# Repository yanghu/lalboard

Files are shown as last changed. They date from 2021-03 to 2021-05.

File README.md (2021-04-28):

##### lalboard - A 3D-printed keyboard inspired by the DataHand.

Note: The v2 branch has been deprecated in favor of the [v2_no_stls](https://github.com/JesusFreke/lalboard/tree/v2_no_stls) branch.

The new branch has the exported stls in a separate repository, to help avoid large checkouts when cloning
the base repository.

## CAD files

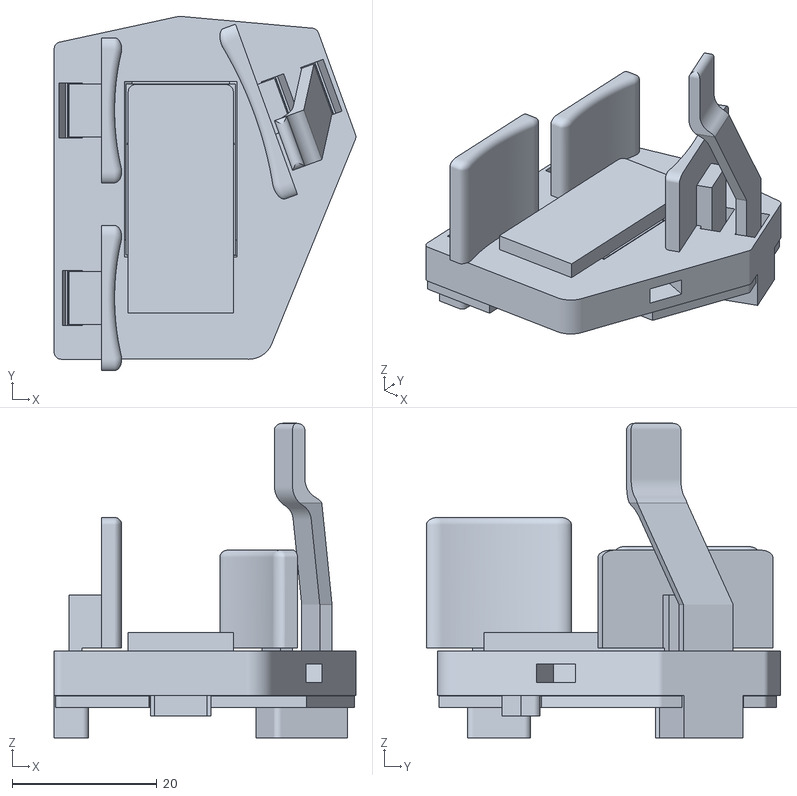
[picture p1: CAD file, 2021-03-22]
stls/thumb_cluster_left_assembly.stl
41.6 x 48.8 x 43.4

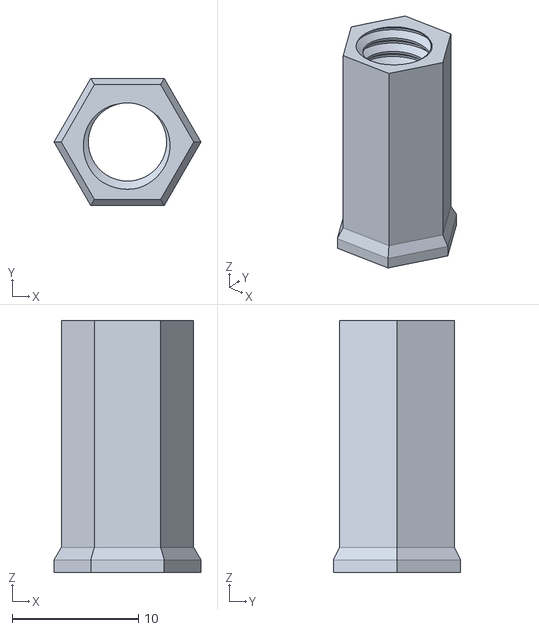
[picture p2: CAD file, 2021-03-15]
stls/screw_base_20.stl
11.7 x 10.1 x 20.0

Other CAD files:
stls/thumb_cluster_right_assembly.stl

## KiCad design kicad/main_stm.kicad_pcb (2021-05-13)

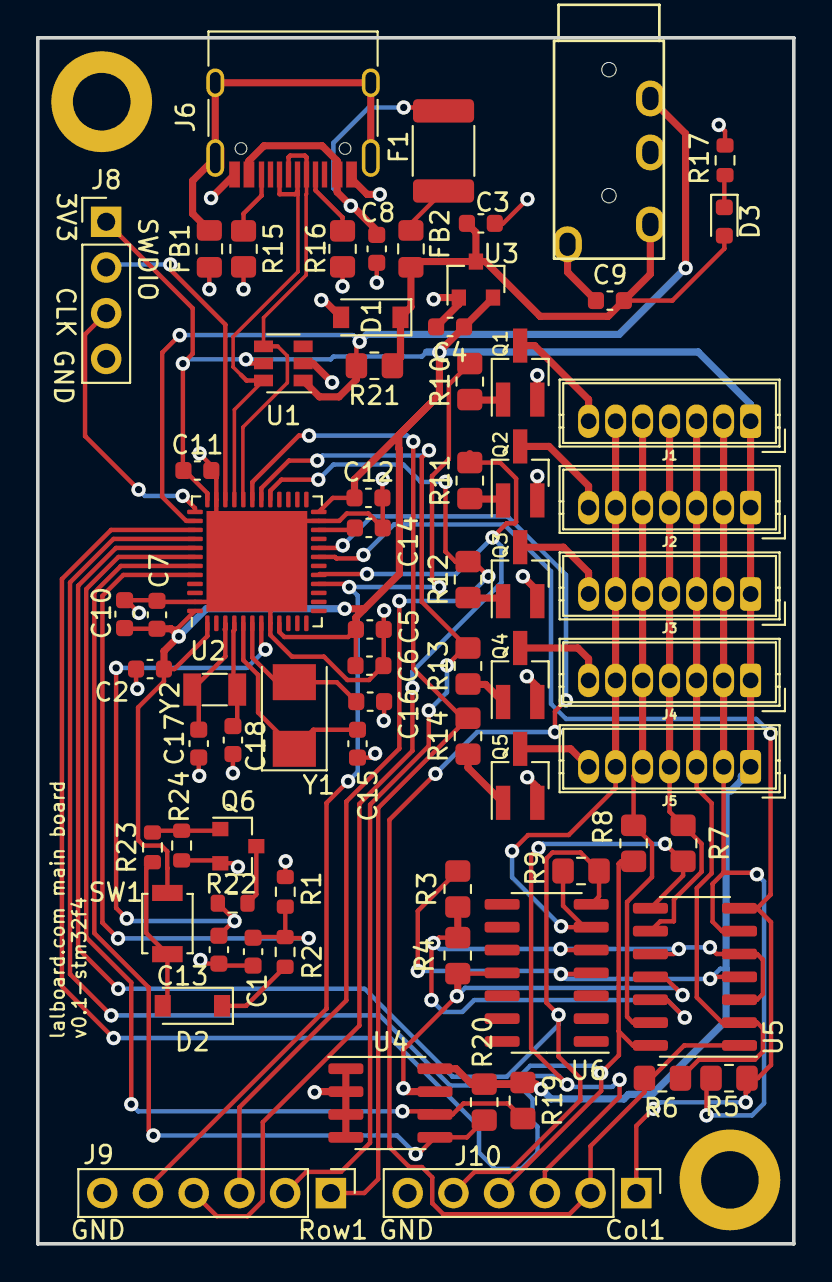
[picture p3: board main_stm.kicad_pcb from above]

Board: 2 copper layers, 42.0 x 67.0 mm, 74 parts (0 on the bottom side), 53 nets.

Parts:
C1, C7: 10uF; C_0603_1608Metric
C2, C6, C8, C9, C10, C11, C12, C13: 0.1uF; C_0603_1608Metric
C3, C4, C5: 1uF; C_0603_1608Metric
C14: 4.7uF; C_0603_1608Metric
C15, C16: 20pF; C_0603_1608Metric
C17, C18: 1.5pF; C_0603_1608Metric
D1: SMF9.0CA; D_SOD-123
D2: 1N4148; D_SOD-123
D3: LED; LED_0603_1608Metric
F1: JK-MSMD050; Fuse_1812_4532Metric_Pad1.30x3.40mm_HandSolder
FB1, FB2: ACML-0805-500-T; L_0805_2012Metric_Pad1.15x1.40mm_HandSolder
H1, H2: MountingHole_Pad; MountingHole_3.2mm_M3_DIN965_Pad
J1, J2, J3, J4, J5: Conn_01x07; JST_ZH_B7B-ZR_1x07_P1.50mm_Vertical
J6: TYPE-C-31-M-12; USB_C_Receptacle_HRO_TYPE-C-31-M-12
J7: AudioJack4; TRRS-PJ-320Atrrs
J8: Conn_01x04; PinHeader_1x04_P2.54mm_Vertical
J9, J10: Conn_01x06; PinHeader_1x06_P2.54mm_Vertical
Q1, Q2, Q3, Q4, Q5: Q_NPN_BEC; SOT-23_Handsoldering
Q6: MMBT3904; SOT-23
R1: 1M; R_0603_1608Metric
R2: 330k; R_0603_1608Metric
R3: 100k; R_0805_2012Metric_Pad1.20x1.40mm_HandSolder
R4: 390k; R_0805_2012Metric_Pad1.20x1.40mm_HandSolder
R5, R6, R7, R8, R9: 2k; R_0805_2012Metric_Pad1.20x1.40mm_HandSolder
R10, R11, R12, R13, R14: 1.5k; R_0805_2012Metric_Pad1.20x1.40mm_HandSolder
R15, R16: 5.1k; R_0805_2012Metric_Pad1.20x1.40mm_HandSolder
R17: 470; R_0603_1608Metric
R19, R20: 4.7k; R_0805_2012Metric_Pad1.20x1.40mm_HandSolder
R21: 10k; R_0805_2012Metric_Pad1.20x1.40mm_HandSolder
R22: 100; R_0603_1608Metric
R23: 2.2k; R_0603_1608Metric
R24: 47k; R_0603_1608Metric
SW1: SW_Push; SW_SPST_B3U-1000P
U1: SRV05-4; SOT-23-6
U2: STM32F411CCUx; QFN-48-1EP_7x7mm_P0.5mm_EP5.6x5.6mm
U3: XC6206PxxxMR; SOT-23
U4: CAT24C256; SOIC-8_3.9x4.9mm_P1.27mm
U5, U6: LMV324; SOIC-14_3.9x8.7mm_P1.27mm
Y1: 8MHz; Crystal_SMD_5032-2Pin_5.0x3.2mm
Y2: 32.768KHz; Crystal_SMD_3215-2Pin_3.2x1.5mm

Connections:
+3V3: C2.1, C4.1, C5.1, C6.1, C7.1, C10.1, C11.1, C12.1, J1.1, J2.1, J3.1, J4.1, J5.1, J8.1, R3.1, R19.1, R20.1, SW1.1, U1.5, U2.1, U2.9, U2.24, U2.36, U2.48, U3.2, U4.8, U5.4, U6.4
+5V: C3.1, C9.2, D1.1, D3.2, FB2.1, J7.T, R21.1, U3.3
/AMP_REF: R3.2, R4.1, U5.3, U5.5, U5.10, U5.12, U6.5
/COL1: J1.2, J2.2, J3.2, J4.2, J5.2, R5.2, U5.6
/COL1_AMP: J10.1, R5.1, U2.19, U5.7
/COL2: J1.3, J2.3, J3.3, J4.3, J5.3, R6.2, U5.2
/COL2_AMP: J10.2, R6.1, U2.20, U5.1
/COL3: J1.4, J2.4, J3.4, J4.4, J5.4, R7.2, U5.9
/COL3_AMP: J10.3, R7.1, U2.39, U5.8
/COL4: J1.5, J2.5, J3.5, J4.5, J5.5, R8.2, U5.13
/COL4_AMP: J10.4, R8.1, U2.40, U5.14
/COL5: J1.6, J2.6, J3.6, J4.6, J5.6, R9.2, U6.6
/COL5_AMP: J10.5, R9.1, U2.41, U6.7
/D+: J6.A6, J6.B6, U1.6, U2.33
/D-: J6.A7, J6.B7, U1.4, U2.32
/ROW1: J9.1, R14.2, U2.31
/ROW2: J9.2, R13.2, U2.30
/ROW3: J9.3, R12.2, U2.29
/ROW4: J9.4, R11.2, U2.17
/ROW5: J9.5, R10.2, U2.16
/SCL: R19.2, U2.42, U4.6
/SDA: R20.2, U2.43, U4.5
/SWCLK: J8.3, U2.37
/SWDIO: J8.2, U2.34
/U1TX: J7.R2, R21.2, U1.1, U2.38
/stm32f411/BOOT0: C1.1, R1.1, R2.1, U2.44
/stm32f411/NRST: C13.2, R22.1, U2.7
/stm32f411/VCAP1: C14.2, U2.22
GND: C1.2, C2.2, C3.2, C4.2, C5.2, C6.2, C7.2, C8.2, C9.1, C10.2, C11.2, C12.2, C13.1, C14.1, C15.2, C16.2, C17.2, C18.2, D1.2, FB1.2, H1.1, H2.1, J6.A1, J6.A12, J6.B1, J6.B12, J7.S, J8.4, J9.6, J10.6, Q1.2, Q2.2, Q3.2, Q4.2, Q5.2, Q6.2, R1.2, R4.2, R15.2, R16.2, R17.1, R24.2, U1.2, U2.8, U2.23, U2.35, U2.47, U2.49, U3.1, U4.1, U4.2, U4.3, U4.4, U4.7, U5.11, U6.11
unnamed: C8.1, F1.2, J6.A4, J6.A9, J6.B4, J6.B9
unnamed: C15.1, U2.5, Y1.1
unnamed: C16.1, U2.6, Y1.2
unnamed: C17.1, U2.3, Y2.1
unnamed: C18.1, U2.4, Y2.2
unnamed: D2.1, R2.2
unnamed: D2.2, R23.1, SW1.2
unnamed: D3.1, R17.2
unnamed: F1.1, FB2.2
unnamed: FB1.1, J6.S1
unnamed: J1.7, Q1.3
unnamed: J2.7, Q2.3
unnamed: J3.7, Q3.3
unnamed: J4.7, Q4.3
unnamed: J5.7, Q5.3
unnamed: J6.A5, R16.1
unnamed: J6.B5, R15.1
unnamed: Q1.1, R10.1
unnamed: Q2.1, R11.1
unnamed: Q3.1, R12.1
unnamed: Q4.1, R13.1
unnamed: Q5.1, R14.1
unnamed: Q6.1, R23.2, R24.1
unnamed: Q6.3, R22.2

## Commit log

2021-03-12 Add a new "export_parts.py" script, and regenerate all the .stls
    [ballscrew_base_tiny.stl, ballscrew_cap.stl, ballscrew_tiny.stl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]
2021-03-12 Add an extra .1mm of height to the top of the cluster
    This ensures there are 2 .2mm layers on top of the PTs/LEDs.
2021-03-12 Flatten out the bottom of the key well and shorten it by .6mm
    This truncates the "V" bottom, so we can shorten the bottom of the key well
    a bit.
    This will make the outside bottoms of the keywell nearly flush with the
    back of the pcb, to enable the use of a 90 degree connector, that would
    otherwise intersect the keywell sticking out past the pcb.
    This also has some other minor tweaks to ensure horizontal surfaces are
    multiples of .2mm away from the print surface (for printing with .2mm
    layer height)
2021-03-12 Spread out the optical components for the north key
    This gives enough room to place a 90 degree connector on the back
2021-03-12 Make the screw bases a bit thinner
    This gives more room for adjacent bases at the back of the clusters
2021-03-12 Bring in the width of the screw base support even more
    This allows yet closer spacing of 2 adjacent support bases (and thus,
    clusters).
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2021-03-15 Fix the orientation of the magnet void in the base for the screw supports
    The void was flipped vertically, so that the widening insertion taper was
    at the bottom of the hole. This also embiggens the holes slightly, to make
    sure they're able to slip in.
2021-03-15 Add the ability to export sketches as .dxf to export_parts.py
    This also updates all the exported parts files.
    [cluster.stl, cluster_front_mount_clip.stl, cluster_front_mount_clip_tall.stl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]
2021-03-15 Fix the pad sizes on the cluster pcb design
    The custom sizes had apparently gotten lost in the last commit
    for the kicad stuff.
    [cluster.kicad_pcb]
2021-03-15 Remove the front nubbins of the cluster pcb
    They were originally intended to be held down by a clip in the front, but
    that's not really needed now, with the screw holding the pcb down.
    [cluster_pcb_sketch.dxf]
2021-03-15 Ensure all 4 bottom vertical edges of the north keywell are filleted
    This ensures it can fit into the routed hole in the PCB, since it will have
    radiused corners from the milling operation
2021-03-15 Fillet the post and corresponding hole in the cluster for the center key
    This ensures the center key post will fit through the milled hole with
    radiused corners in the PCB.
2021-03-15 Don't fillet the center key hole in the cluster
    Only the center key post itself needs to be Filleted. The hole itself can
    remain square. The corners provide a good place for the slicer to place a
    seam, where it won't interfere with the fit of the key.
2021-03-15 Fillet the center hole in the cluster pcb, and adjust its offset
2021-03-15 Fillet the internal corners of the square protrusion on the back of the pcb
    This ensures all of the internal corners are filleted, for consistency.
2021-03-16 Move the cluster pcb connector back as far as possible
    Now that we've switched to the horizontal connector, we can push the
    connector back a bit, since it requires less clearance behind it.
    I *think* this gets the connector far away enough (barely) from the LED
    and PT for the central key that the wire can be plugged in.
2021-03-16 Update the kicad design for the finger cluster
    This brings the PCB design up to par with the current cluster design.
    [cluster.kicad_pcb, cluster.sch]
2021-03-17 Update kicad design for finger cluster
    This adds ground/+5v planes, some thicker traces, and moves the +5v pin
    to pin 1 of the connector.
    Thanks to @rutgervana for taking a look at the design and making
    suggestions/showing example improvements.
    [cluster.kicad_pcb, cluster.sch]
2021-03-17 Rotate the cluster pcb part by 180, and tweak how the sketch is created
    This matches the orientation used in the kicad design.
    Kicad didn't like the previous dxf export for some reason. But with the
    sketch defined this way, it seems to work fine.
2021-03-17 Rename cluster_key_long to cluster_key_tall
    "tall" is the more appropriate opposite of "short" in this context.
    [cluster_key_tall.stl]
2021-03-17 Extract the screw nut design out to a separate method in lalboard.py
    This allows it to be used in other assemblies without having to specify
    its parameters in multiple places.
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2021-03-18 Add support for generating various exports for assemblies in export_parts.py
    This will export an assembly as an stl, an f3d, and to a specific
    fusion 360 cloud instance (which can then be shared via link, for viewing
    on the web by anyone)
    [cluster.stl, cluster_assembly.f3d, cluster_body_assembly.f3d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]
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2021-03-18 Rename "full_thumb" design method to "thumb_assembly"
    This makes it more consistent with the finger cluster naming
2021-03-18 Fix the key alignment in the thumb cluster assemblies, and re-enable them
2021-03-19 Remove the thumb clip
    Instead, we'll add screws to secure the pcb
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2021-03-19 Add a virtual "locating pin" to the cluster pcb sketch
    This gives a reference point for the origin of the sketch, so the import
    location can be set correctly when importing the outline into kicad.
    Basically, you set the grid origin in kicad to the center of the circle
    (assuming the locating pin is already in kicad) and then make a note of
    the coordinates of that point. And then, when importing the outline, you
    can specify those coordinates as the location, to ensure the origin of the
    imported outline matches that of the existing/previous outline.
    [cluster.kicad_pcb, cluster_pcb_sketch.dxf]
2021-03-19 Fix how assemblies are exported to the fusion cloud
2021-03-19 Add _sketch parts for the thumb pcbs, to generate the outline .dxf files.
    [cluster_assembly.f3d, cluster_body_assembly.f3d, cluster_body_assembly.stl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]
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2021-03-20 Fillet the remaining sharp corners on the thumb cluster
    It seems silly to have 2 sharp corners, with the rest being filleted
    [thumb_cluster_insertion_tool.stl, thumb_cluster_left.stl, thumb_cluster_left_assembly.f3d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]
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2021-03-20 Add a fillet to the cutout in the thumb pcb for the down key
    This also fillets the sticky-down part of the keywell for the down-key,
    to match the fillet in the pcb.
    [cluster.stl, cluster_assembly.f3d, cluster_body_assembly.f3d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]
2021-03-22 Tweak the screw positions for the thumb cluster
    Minor tweaks to improve the pcb placement of the screw holes
    [thumb_pcb_left_sketch.dxf]
2021-03-22 Update the design of the left thumb cluster pcb
    [thumb_cluster_left.kicad_pcb, thumb_cluster_left.sch]
2021-03-22 Minor tweaks to the cluster pcb
    - Move the identifying text to the bottom layer
    - Disable some unused layers
    - Move the design so that the import position is at an even (150, 100)
    [cluster.kicad_pcb]
2021-03-22 Fix thumb_pcb_right_sketch.py
    It was mirrored, like the left clustered.
    [thumb_pcb_right_sketch.dxf]
2021-03-22 Update the design of the right thumb cluster pcb
    [thumb_cluster_right.kicad_pcb, thumb_cluster_right.sch]
2021-03-22 Fix the thumb assemblies
    There was something funky going on with the Group component
2021-03-22 Update all the exported stls, etc.
    [cluster_assembly.f3d, cluster_body_assembly.f3d, cluster_body_assembly.stl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]
2021-03-22 Fix up the cluster and thumb_cluster_left pcbs
    Some of the nets for the pours and screw holes had gotten unassigned
    somehow
    [cluster.kicad_pcb, thumb_cluster_left.kicad_pcb]
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2021-03-22 Update the exported thumb parts
    [thumb_cluster_left.stl, thumb_cluster_left_assembly.f3d, thumb_cluster_right.stl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]
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2021-04-28 Deprecate the v2 branch
    [central_pcb.stl, central_pcb_tray.stl, cluster.kicad_pcb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]
2021-05-13 Add stm32 version of main board
    [main_stm.kicad_pcb, main_stm.sch, stm32f411.sch]
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2021-05-13 adjust silkscreen of main stm pcb
    [main_stm.kicad_pcb]
2021-05-16 minor fix to stm32 schema
    [stm32f411.sch]
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
